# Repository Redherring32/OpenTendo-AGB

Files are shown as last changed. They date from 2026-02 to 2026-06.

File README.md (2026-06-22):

# OpenTendo Game Boy Advance (OpenGBA)

This is an open source recreation of the AGB-CPU-01 board. This was a joint effort between Redherring32 and Bucket Mouse (Mousebitelabs) - initial board scans, copper tracing, and footprint generation were done by Redherring32; schematic and symbol generation, PCB copper cleanup, and silkscreen were done by Bucket Mouse. This is a close to 1:1 recreation of the original AGB-CPU-01 circuit board - some liberties were taken here and there to ensure ease of manufacturability (namely, 6 mil spacing) and to improve aesthetics (most vias are *tented* rather than untented).





## File Structure

**Board Files**: contains the schematics and PCB files for KiCad 9.0

**Footprints/OpenTendo-AGB.pretty**: component footprints for KiCad 9.0

**Symbols**: component symbols for KiCad 9.0

**Bill_of_Materials.csv**: a list of components and component values for each part on the board (see [this site](https://docs.google.com/spreadsheets/d/17RfgOaR-P8M0cC5BojwuY52GbZUefLFm82To7ja963o/edit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) for some alternatives)

**Gerbers.zip**: files used to order circuit boards from manufacturers (JLCPCB, PCBway, etc.)

## Board Characteristics and Order Information

The zipped folder contains all the gerber files for this board. The following options **must** be chosen when ordering boards for yourself.

- Thickness: 1.0mm
- Surface Finish: ENIG

## License
<br />This work is licensed under a <a rel="license" href="http://creativecommons.org/licenses/by-sa/4.0/">Creative Commons Attribution-ShareAlike 4.0 International License</a>. You are able to copy and redistribute the material in any medium or format, as well as remix, transform, or build upon the material for any purpose (even commercial) - but you **must** give appropriate credit, provide a link to the license, and indicate if any changes were made.

©Redherring32 2023-2026

©MouseBiteLabs 2026

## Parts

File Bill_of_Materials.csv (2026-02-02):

Reference | Qty | Value | DNP | Exclude from BOM | Exclude from Board | Footprint | Datasheet
BT1 | 1 | Battery |  |  |  | OpenTendo-AGB:Battery | ~
C1,C37,C62,C63,C64 | 5 | 0.01u |  |  |  | OpenTendo-AGB:C_0402_1005Metric | ~
C2,C24,C28,C30,C38,C42,C57,C61 | 8 | 1u |  |  |  | OpenTendo-AGB:C_0603_1608Metric | ~
C3 | 1 | 27p |  |  |  | OpenTendo-AGB:C_0402_1005Metric | ~
C4 | 1 | 33p |  |  |  | OpenTendo-AGB:C_0402_1005Metric | ~
C5,C6,C7,C8,C13,C14,C15,C16,C17,C22,C23,C26,C32,C34,C39,C40,C41,C45,C46,C47,C50,C51,C52,C53,C55,C58,C59 | 27 | 0.1u |  |  |  | OpenTendo-AGB:C_0402_1005Metric | ~
C9,C12 | 2 | 1000p |  |  |  | OpenTendo-AGB:C_0402_1005Metric | ~
C10,C18,C19,C20,C49 | 5 | 100p |  |  |  | OpenTendo-AGB:C_0402_1005Metric | ~
C11,C48 | 2 | 470p |  |  |  | OpenTendo-AGB:C_0402_1005Metric | ~
C25 | 1 | 0.47u |  |  |  | OpenTendo-AGB:C_0603_1608Metric | ~
C27,C43,C54 | 3 | 4.7u |  |  |  | OpenTendo-AGB:C_0805_2012Metric | ~
C33,C35,C36 | 3 | 1u |  |  |  | OpenTendo-AGB:C_0805_2012Metric | ~
C44,C56 | 2 | 2.2u |  |  |  | OpenTendo-AGB:C_0805_2012Metric | ~
CL1 | 1 | SolderJumper_2_Bridged |  | Excluded from BOM |  | OpenTendo-AGB:Jumper-Bridged | ~
CP1,CP4 | 2 | 100u |  |  |  | OpenTendo-AGB:CP_Elec_5x5.3 | ~
CP2 | 1 | 100u |  |  |  | OpenTendo-AGB:C_Elec_6.3x5.8 | ~
CP3 | 1 | 470u |  |  |  | OpenTendo-AGB:C_Elec_8x10.2 | ~
D1 | 1 | MA112 |  |  |  | OpenTendo-AGB:Diode | ~
D2 | 1 | RB411D |  |  |  | OpenTendo-AGB:SOT-23 | ~
D3 | 1 | RB491D |  |  |  | OpenTendo-AGB:SOT-23 | ~
D4 | 1 | ISS355 |  |  |  | OpenTendo-AGB:Diode | ~
DA1,DA2 | 2 | DA204U |  |  |  | OpenTendo-AGB:SOT-323 | ~
DL1 | 1 | SML311UT |  |  |  | OpenTendo-AGB:LED_0603_1608Metric | ~
DL2 | 1 | SML210MT |  |  |  | OpenTendo-AGB:LED_0603_1608Metric | ~
DZ1 | 1 | RD4.7S |  |  |  | OpenTendo-AGB:Diode
EM1,EM2 | 2 | ACM4532-102-3P |  |  |  | OpenTendo-AGB:EM | ~
EM3,EM7 | 2 | HW601 |  |  |  | OpenTendo-AGB:L_0603_1608Metric | ~
EM4,EM5,EM6 | 3 | BLM11B252SD |  |  |  | OpenTendo-AGB:L_0603_1608Metric | ~
F1 | 1 | 4341.25 |  |  |  | OpenTendo-AGB:Fuse_0603_1608Metric | ~
L1 | 1 | 100u |  |  |  | OpenTendo-AGB:Inductor | ~
P1 | 1 | CART |  |  |  | OpenTendo-AGB:CartSlot
P2 | 1 | LCD |  |  |  | OpenTendo-AGB:LCD-Connector
P3 | 1 | PHONE JACK |  |  |  | OpenTendo-AGB:Audio-Jack
P4 | 1 | AGB-LINK |  |  |  | OpenTendo-AGB:EXT
Q1 | 1 | DTA123J |  |  |  | OpenTendo-AGB:SOT-323
Q2 | 1 | DTA114T |  |  |  | OpenTendo-AGB:SOT-323
Q3,Q10 | 2 | DTC114Y |  |  |  | OpenTendo-AGB:SOT-323
Q4,Q5 | 2 | FDV303N |  |  |  | OpenTendo-AGB:SOT-23 | ~
Q6 | 1 | 2SK1582 |  |  |  | OpenTendo-AGB:SOT-23 | ~
Q7 | 1 | SSM3J01F |  |  |  | OpenTendo-AGB:SOT-23 | ~
Q8,Q9 | 2 | 2SC4081 |  |  |  | OpenTendo-AGB:SOT-323 | ~
Q11 | 1 | DTA114Y |  |  |  | OpenTendo-AGB:SOT-323
R1 | 1 | 1.5M |  |  |  | OpenTendo-AGB:R_0402_1005Metric | ~
R2 | 1 | 10k |  |  |  | OpenTendo-AGB:R_0402_1005Metric | ~
R3,R4,R7,R8,R30,R31 | 6 | 47k |  |  |  | OpenTendo-AGB:R_0402_1005Metric | ~
R5,R6,R17,R35 | 4 | 100k |  |  |  | OpenTendo-AGB:R_0402_1005Metric | ~
R10,R37 | 2 | 470 |  |  |  | OpenTendo-AGB:R_0402_1005Metric | ~
R11,R12,R13 | 3 | 150 |  |  |  | OpenTendo-AGB:R_0402_1005Metric | ~
R14 | 1 | 4.7k |  |  |  | OpenTendo-AGB:R_0402_1005Metric | ~
R15,R16,R18 | 3 | 33k |  |  |  | OpenTendo-AGB:R_0402_1005Metric | ~
R19,R20,R40,R43,R44 | 5 | 15 |  |  |  | OpenTendo-AGB:R_0402_1005Metric | ~
R25,R38,R39 | 3 | 47 |  |  |  | OpenTendo-AGB:R_0402_1005Metric | ~
R26,R34 | 2 | 15k |  |  |  | OpenTendo-AGB:R_0402_1005Metric | ~
R27 | 1 | 200k |  |  |  | OpenTendo-AGB:R_0402_1005Metric | ~
R28 | 1 | 56k |  |  |  | OpenTendo-AGB:R_0402_1005Metric | ~
R29 | 1 | 18k |  |  |  | OpenTendo-AGB:R_0402_1005Metric | ~
R32 | 1 | 1M |  |  |  | OpenTendo-AGB:R_0402_1005Metric | ~
R33 | 1 | 5.1 |  |  |  | OpenTendo-AGB:R_0402_1005Metric | ~
R36 | 1 | 270 |  |  |  | OpenTendo-AGB:R_0402_1005Metric | ~
R41 | 1 | 2.2k |  |  |  | OpenTendo-AGB:R_0402_1005Metric | ~
RA1 | 1 | 330 |  |  |  | OpenTendo-AGB:RA
SP1 | 1 | Speaker |  |  |  | OpenTendo-AGB:Speaker | ~
SW1 | 1 | AGB-SW |  |  |  | OpenTendo-AGB:Power Switch
SW2 | 1 | SW_Push |  |  |  | OpenTendo-AGB:L | ~
SW3 | 1 | SW_Push |  |  |  | OpenTendo-AGB:R | ~
SW4 | 1 | AGB-A-B |  |  |  | OpenTendo-AGB:AB | ~
SW5 | 1 | AGB-ST-SEL |  |  |  | OpenTendo-AGB:StartSelect
SW6 | 1 | AGB-DPAD |  |  |  | OpenTendo-AGB:DPAD
T1 | 1 | AGB-XFRM |  |  |  | OpenTendo-AGB:Coil
TP0 | 1 | TP0 |  |  |  | OpenTendo-AGB:TestPoint_Pad_D1.0mm
TP1 | 1 | TP1 |  |  |  | OpenTendo-AGB:TestPoint_Pad_D1.0mm
TP2 | 1 | TP2 |  |  |  | OpenTendo-AGB:TestPoint_Pad_D0.8mm
TP3 | 1 | TP3 |  |  |  | OpenTendo-AGB:TestPoint_Pad_D0.8mm
TP4 | 1 | TP4 |  |  |  | OpenTendo-AGB:TestPoint_Pad_D0.8mm
TP5 | 1 | TP5 |  |  |  | OpenTendo-AGB:TestPoint_Pad_D1.0mm
TP6 | 1 | TP6 |  |  |  | OpenTendo-AGB:TestPoint_Pad_D0.8mm
TP7 | 1 | TP7 |  |  |  | OpenTendo-AGB:TestPoint_Pad_D1.0mm
TP8 | 1 | TP8 |  |  |  | OpenTendo-AGB:TestPoint_Pad_D0.8mm_VIA
TP9 | 1 | TP9 |  |  |  | OpenTendo-AGB:TestPoint_Pad_D0.8mm
TP10 | 1 | VOUT3 |  |  |  | OpenTendo-AGB:TestPoint_Pad_D1.0mm_VIA
TP11 | 1 | VDRV3 |  |  |  | OpenTendo-AGB:TestPoint_Pad_D1.0mm
TP12 | 1 | VDD2 |  |  |  | OpenTendo-AGB:TestPoint_Pad_D0.8mm
TP13 | 1 | VDRV5 |  |  |  | OpenTendo-AGB:TestPoint_Pad_D1.0mm
TP14 | 1 | VOUT5 |  |  |  | OpenTendo-AGB:TestPoint_Pad_D0.8mm
TP15 | 1 | ~{RESET} |  |  |  | OpenTendo-AGB:TestPoint_Pad_D1.25mm_VIA
TP16 | 1 | D3A |  |  |  | OpenTendo-AGB:TestPoint_Pad_D1.0mm
TP17 | 1 | D2A |  |  |  | OpenTendo-AGB:TestPoint_Pad_D1.0mm_VIA
TP18 | 1 | DA2-AC |  |  |  | OpenTendo-AGB:TestPoint_Pad_D0.8mm_VIA
TP19 | 1 | DA1-AC |  |  |  | OpenTendo-AGB:TestPoint_Pad_D1.0mm_VIA
TP20 | 1 | DA2-A |  |  |  | OpenTendo-AGB:TestPoint_Pad_D0.8mm
TP21 | 1 | DA1-C |  |  |  | OpenTendo-AGB:TestPoint_Pad_D0.8mm
TP22 | 1 | VDD13 |  |  |  | OpenTendo-AGB:TestPoint_Pad_D0.8mm
TP23 | 1 | VDD-15 |  |  |  | OpenTendo-AGB:TestPoint_Pad_D1.0mm
TP24 | 1 | VDD5 |  |  |  | OpenTendo-AGB:TestPoint_Pad_D1.0mm
TP25 | 1 | Q8B |  |  |  | OpenTendo-AGB:TestPoint_Pad_D0.8mm
TP26 | 1 | VSHD |  |  |  | OpenTendo-AGB:TestPoint_Pad_D0.8mm
TP27 | 1 | Q10B |  |  |  | OpenTendo-AGB:TestPoint_Pad_D0.8mm_VIA
TP28 | 1 | LOWBAT |  |  |  | OpenTendo-AGB:TestPoint_Pad_D0.8mm
TP29 | 1 | DL2A |  |  |  | OpenTendo-AGB:TestPoint_Pad_D0.8mm_VIA
TP30 | 1 | DL2K |  |  |  | OpenTendo-AGB:TestPoint_Pad_D0.8mm_VIA
TP31 | 1 | DL1A |  |  |  | OpenTendo-AGB:TestPoint_Pad_D0.8mm_VIA
TP32 | 1 | D1A |  |  |  | OpenTendo-AGB:TestPoint_Pad_D0.8mm_VIA
TP33 | 1 | Q9C |  |  |  | OpenTendo-AGB:TestPoint_Pad_D1.0mm
TP34 | 1 | Q9B |  |  |  | OpenTendo-AGB:TestPoint_Pad_D0.8mm
TP35 | 1 | Q11B |  |  |  | OpenTendo-AGB:TestPoint_Pad_D0.8mm_VIA
TP36 | 1 | MOD |  |  |  | OpenTendo-AGB:TestPoint_Pad_D0.8mm_VIA
TP37 | 1 | SPS |  |  |  | OpenTendo-AGB:TestPoint_Pad_D0.8mm_VIA
TP38 | 1 | CLS |  |  |  | OpenTendo-AGB:TestPoint_Pad_D0.8mm_VIA
TP39 | 1 | SPL |  |  |  | OpenTendo-AGB:TestPoint_Pad_D0.8mm_VIA
TP40 | 1 | LDB1 |  |  |  | OpenTendo-AGB:TestPoint_Pad_D0.8mm_VIA
TP41 | 1 | LDB2 |  |  |  | OpenTendo-AGB:TestPoint_Pad_D0.8mm_VIA
TP42 | 1 | LDB3 |  |  |  | OpenTendo-AGB:TestPoint_Pad_D0.8mm_VIA
TP43 | 1 | LDB4 |  |  |  | OpenTendo-AGB:TestPoint_Pad_D0.8mm_VIA
TP44 | 1 | LDB5 |  |  |  | OpenTendo-AGB:TestPoint_Pad_D0.8mm_VIA
TP45 | 1 | LDG1 |  |  |  | OpenTendo-AGB:TestPoint_Pad_D0.8mm_VIA
TP46 | 1 | LDG2 |  |  |  | OpenTendo-AGB:TestPoint_Pad_D0.8mm_VIA
TP47 | 1 | LDG3 |  |  |  | OpenTendo-AGB:TestPoint_Pad_D0.8mm_VIA
TP48 | 1 | LDG4 |  |  |  | OpenTendo-AGB:TestPoint_Pad_D0.8mm_VIA
TP49 | 1 | LDG5 |  |  |  | OpenTendo-AGB:TestPoint_Pad_D0.8mm_VIA
TP50 | 1 | LDR1 |  |  |  | OpenTendo-AGB:TestPoint_Pad_D0.8mm_VIA
TP51 | 1 | LDR2 |  |  |  | OpenTendo-AGB:TestPoint_Pad_D0.8mm_VIA
TP52 | 1 | LDR3 |  |  |  | OpenTendo-AGB:TestPoint_Pad_D0.8mm_VIA
TP53 | 1 | LDR4 |  |  |  | OpenTendo-AGB:TestPoint_Pad_D0.8mm_VIA
TP54 | 1 | LDR5 |  |  |  | OpenTendo-AGB:TestPoint_Pad_D0.8mm_VIA
TP55 | 1 | PS |  |  |  | OpenTendo-AGB:TestPoint_Pad_D0.8mm_VIA
TP56 | 1 | LP |  |  |  | OpenTendo-AGB:TestPoint_Pad_D0.8mm_VIA
TP57 | 1 | DCK |  |  |  | OpenTendo-AGB:TestPoint_Pad_D0.8mm
TP58 | 1 | P2-VSS |  |  |  | OpenTendo-AGB:TestPoint_Pad_D0.8mm
TP59 | 1 | P2-VCC |  |  |  | OpenTendo-AGB:TestPoint_Pad_D0.8mm
TP60 | 1 | P2-VDD |  |  |  | OpenTendo-AGB:TestPoint_Pad_D0.8mm_VIA
TP61 | 1 | P2-VEE |  |  |  | OpenTendo-AGB:TestPoint_Pad_D0.8mm_VIA
TP62 | 1 | REVC |  |  |  | OpenTendo-AGB:TestPoint_Pad_D0.8mm
TP63 | 1 | U3-VDD |  |  |  | OpenTendo-AGB:TestPoint_Pad_D0.8mm
TP64 | 1 | V0 |  |  |  | OpenTendo-AGB:TestPoint_Pad_D0.8mm
TP65 | 1 | V1 |  |  |  | OpenTendo-AGB:TestPoint_Pad_D0.8mm
TP66 | 1 | V2 |  |  |  | OpenTendo-AGB:TestPoint_Pad_D0.8mm
TP67 | 1 | V3 |  |  |  | OpenTendo-AGB:TestPoint_Pad_D0.8mm_VIA
TP68 | 1 | V4 |  |  |  | OpenTendo-AGB:TestPoint_Pad_D0.8mm
TP69 | 1 | U3-COM |  |  |  | OpenTendo-AGB:TestPoint_Pad_D0.8mm
TP70 | 1 | VCOM |  |  |  | OpenTendo-AGB:TestPoint_Pad_D0.8mm_VIA
TP71 | 1 | VR1-2 |  |  |  | OpenTendo-AGB:TestPoint_Pad_D0.8mm_VIA
TP72 | 1 | U5-3 |  |  |  | OpenTendo-AGB:TestPoint_Pad_D0.8mm_VIA
TP73 | 1 | Q3B |  |  |  | OpenTendo-AGB:TestPoint_Pad_D0.8mm_VIA
TP74 | 1 | Q1B |  |  |  | OpenTendo-AGB:TestPoint_Pad_D0.8mm_VIA
TP75 | 1 | IN35 |  |  |  | OpenTendo-AGB:TestPoint_Pad_D1.0mm_VIA
TP76 | 1 | VDD35 |  |  |  | OpenTendo-AGB:TestPoint_Pad_D1.0mm
TP77 | 1 | PHI |  |  |  | OpenTendo-AGB:TestPoint_Pad_D1.0mm
TP78 | 1 | RES |  |  |  | OpenTendo-AGB:TestPoint_Pad_D0.8mm_VIA
TP79 | 1 | P1-GND |  |  |  | OpenTendo-AGB:TestPoint_Pad_D1.0mm
TP80 | 1 | CK1 |  |  |  | OpenTendo-AGB:TestPoint_Pad_D0.8mm
TP81 | 1 | CK2 |  |  |  | OpenTendo-AGB:TestPoint_Pad_D0.8mm
TP82 | 1 | FIQ |  |  |  | OpenTendo-AGB:TestPoint_Pad_D1.25mm_VIA
TP83 | 1 | SW1-2 |  |  |  | OpenTendo-AGB:TestPoint_Pad_D1.25mm
TP84 | 1 | SW1-1 |  |  |  | OpenTendo-AGB:TestPoint_Pad_D0.8mm
TP85 | 1 | VCC |  |  |  | OpenTendo-AGB:TestPoint_Pad_D0.8mm
TP86 | 1 | C_SCP |  |  |  | OpenTendo-AGB:TestPoint_Pad_D1.0mm
TP87 | 1 | C_SS5 |  |  |  | OpenTendo-AGB:TestPoint_Pad_D1.0mm
TP88 | 1 | C_SS3 |  |  |  | OpenTendo-AGB:TestPoint_Pad_D1.0mm
TP89 | 1 | VIN |  |  |  | OpenTendo-AGB:TestPoint_Pad_D0.8mm_VIA
TP90 | 1 | REG_EXT |  |  |  | OpenTendo-AGB:TestPoint_Pad_D0.8mm
TP91 | 1 | VCNT5 |  |  |  | OpenTendo-AGB:TestPoint_Pad_D1.0mm
TP92 | 1 | SO |  |  |  | OpenTendo-AGB:TestPoint_Pad_D0.8mm
TP93 | 1 | SD |  |  |  | OpenTendo-AGB:TestPoint_Pad_D0.8mm_VIA
TP94 | 1 | SI |  |  |  | OpenTendo-AGB:TestPoint_Pad_D0.8mm
TP95 | 1 | SCK |  |  |  | OpenTendo-AGB:TestPoint_Pad_D0.8mm_VIA
TP96 | 1 | U6-LIN |  |  |  | OpenTendo-AGB:TestPoint_Pad_D0.8mm
TP97 | 1 | U6-RIN |  |  |  | OpenTendo-AGB:TestPoint_Pad_D0.8mm
TP98 | 1 | FL |  |  |  | OpenTendo-AGB:TestPoint_Pad_D0.8mm
TP99 | 1 | FR |  |  |  | OpenTendo-AGB:TestPoint_Pad_D0.8mm
TP100 | 1 | FL1 |  |  |  | OpenTendo-AGB:TestPoint_Pad_D0.8mm
TP101 | 1 | FL2 |  |  |  | OpenTendo-AGB:TestPoint_Pad_D0.8mm
TP102 | 1 | FR1 |  |  |  | OpenTendo-AGB:TestPoint_Pad_D0.8mm
TP103 | 1 | FR2 |  |  |  | OpenTendo-AGB:TestPoint_Pad_D0.8mm
TP104 | 1 | U6-LOUT |  |  |  | OpenTendo-AGB:TestPoint_Pad_D0.8mm_VIA
TP105 | 1 | U6-ROUT |  |  |  | OpenTendo-AGB:TestPoint_Pad_D0.8mm
TP106 | 1 | VOL |  |  |  | OpenTendo-AGB:TestPoint_Pad_D0.8mm_VIA
TP107 | 1 | VR2-3 |  |  |  | OpenTendo-AGB:TestPoint_Pad_D0.8mm_VIA
TP108 | 1 | VR2-1 |  |  |  | OpenTendo-AGB:TestPoint_Pad_D0.8mm_VIA
TP109 | 1 | LOUT |  |  |  | OpenTendo-AGB:TestPoint_Pad_D0.8mm
TP110 | 1 | ROUT |  |  |  | OpenTendo-AGB:TestPoint_Pad_D0.8mm
TP111 | 1 | SP |  |  |  | OpenTendo-AGB:TestPoint_Pad_D1.25mm_VIA
TP112 | 1 | A-GND |  |  |  | OpenTendo-AGB:TestPoint_Pad_D1.0mm
TP113 | 1 | VDD3 |  |  |  | OpenTendo-AGB:TestPoint_Pad_D0.8mm
TP114 | 1 | R-OUT |  |  |  | OpenTendo-AGB:TestPoint_Pad_D0.8mm
TP115 | 1 | L-OUT |  |  |  | OpenTendo-AGB:TestPoint_Pad_D0.8mm
TP116 | 1 | T1-6 |  |  |  | OpenTendo-AGB:TestPoint_Pad_D1.0mm_VIA
U1 | 1 | AGB-CPU |  |  |  | OpenTendo-AGB:CPU-AGB
U2 | 1 | AGB-SRAM |  |  |  | OpenTendo-AGB:AGB-SRAM
U3 | 1 | AGB-REG |  |  |  | OpenTendo-AGB:AGB-REG
U4 | 1 | AGB-PMIC |  |  |  | OpenTendo-AGB:TSSOP-16_4.4x5mm_P0.65mm
U5 | 1 | UMD2N |  |  |  | OpenTendo-AGB:SOT-363_SC-70-6
U6 | 1 | AGB-AMP |  |  |  | OpenTendo-AGB:AGB-AMP
U10 | 1 | UMG3N |  |  |  | OpenTendo-AGB:SOT-353_SC-70-5
VR1 | 1 | 50k |  |  |  | OpenTendo-AGB:VR1 | ~
VR2 | 1 | 30k |  |  |  | OpenTendo-AGB:Thumbwheel | ~
X1 | 1 | 4.194304MHz |  |  |  | OpenTendo-AGB:Crystal | ~

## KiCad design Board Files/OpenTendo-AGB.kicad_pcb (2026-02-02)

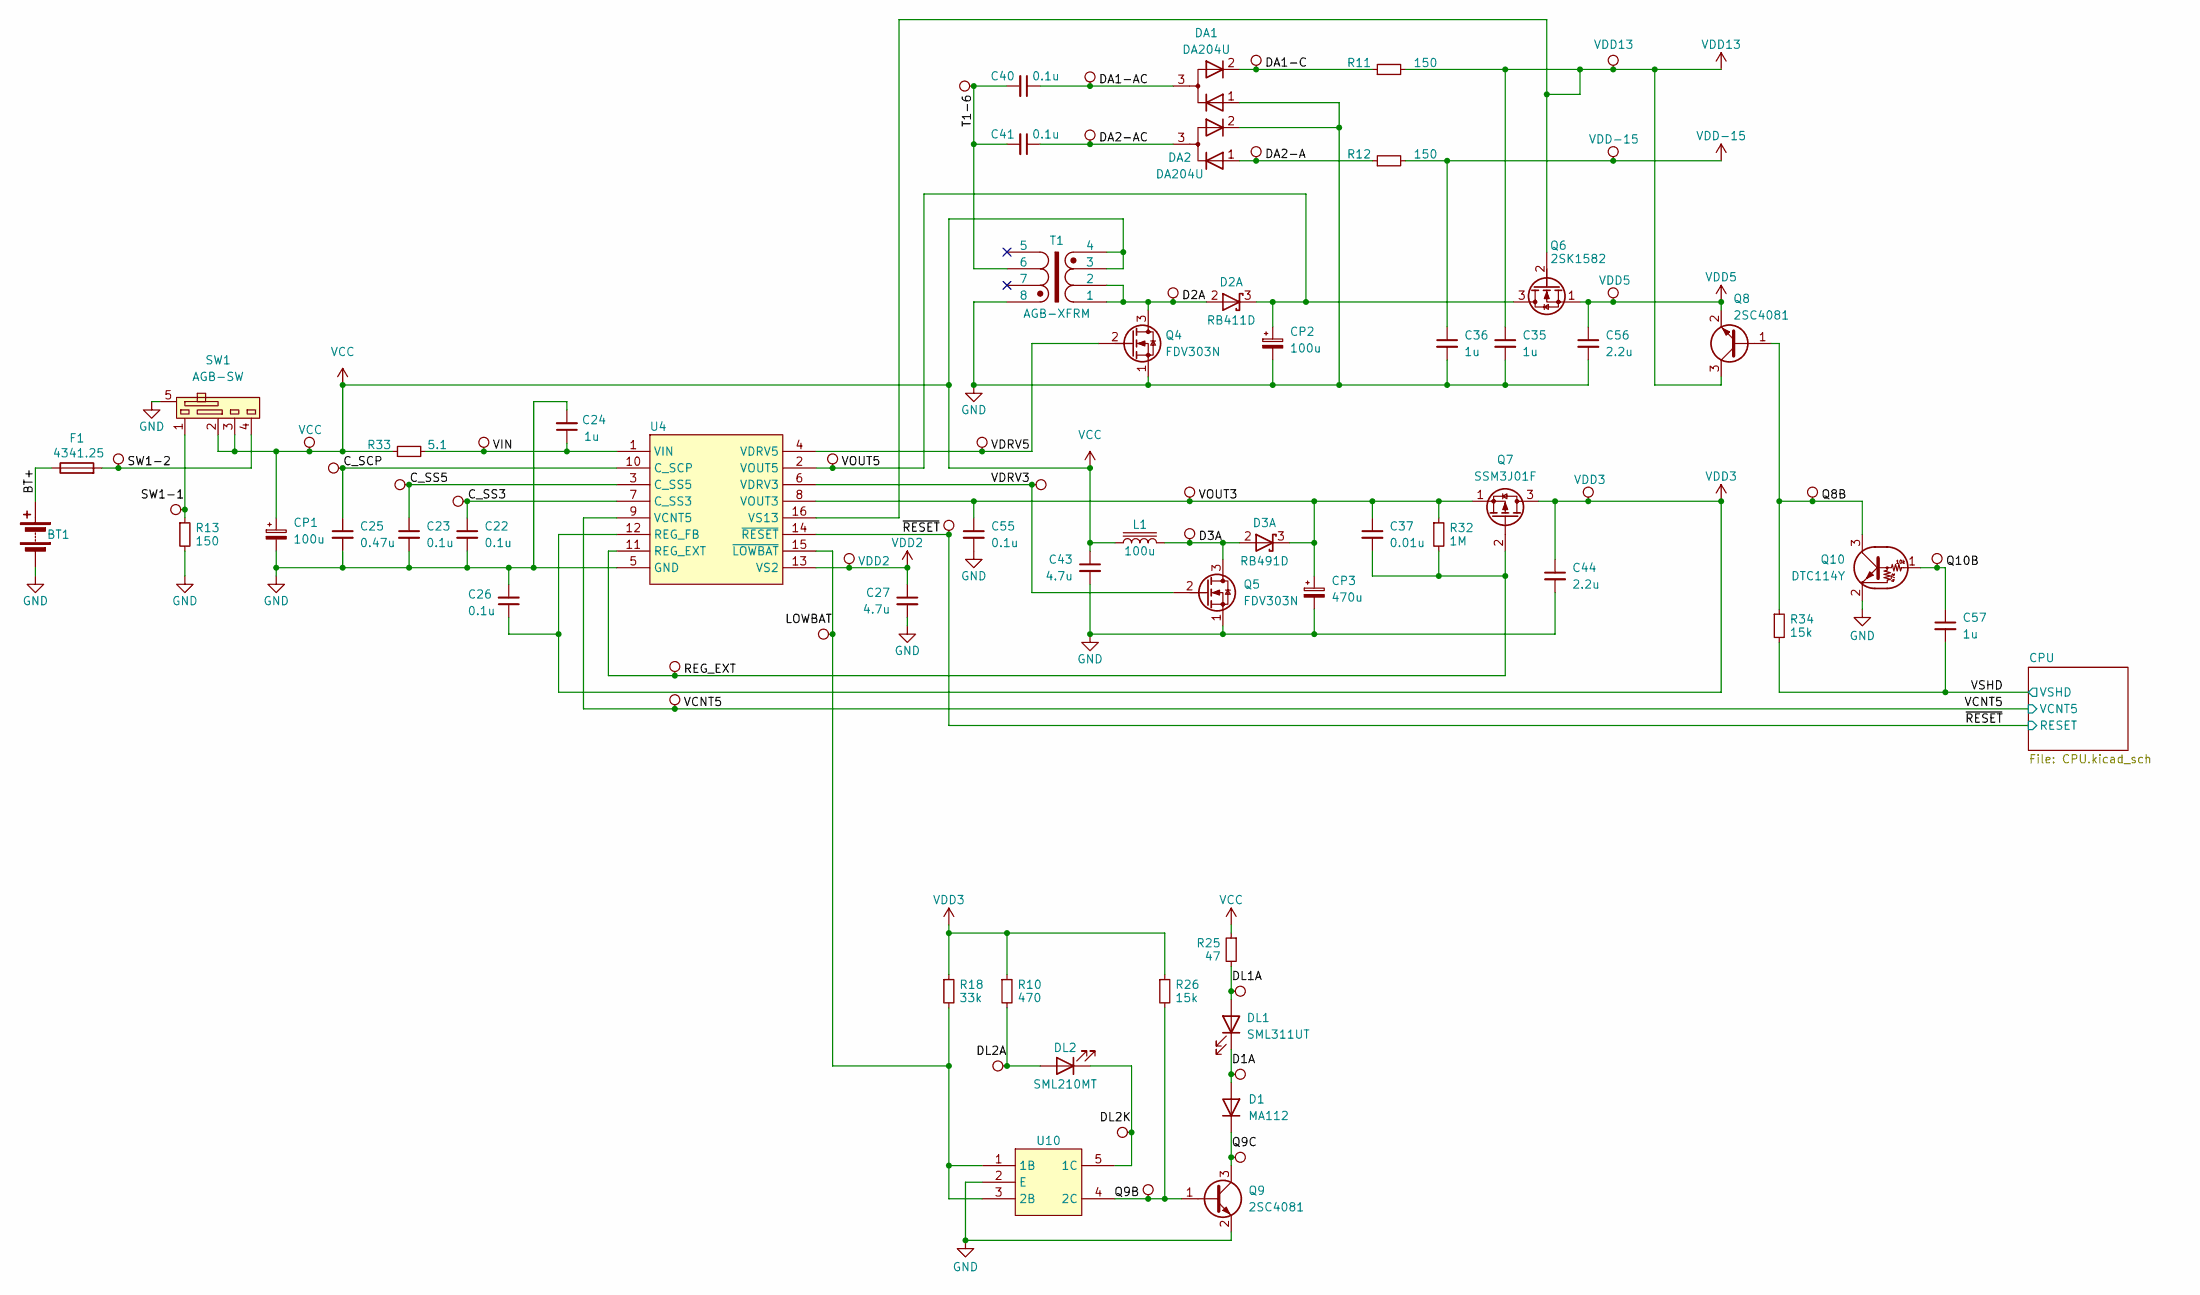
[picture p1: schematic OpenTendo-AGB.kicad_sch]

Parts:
BT1: Battery
C22, C23, C26, C40, C41, C55: 0.1u; C_0402_1005Metric
C24, C57: 1u; C_0603_1608Metric
C25: 0.47u; C_0603_1608Metric
C27, C43: 4.7u; C_0805_2012Metric
C35, C36: 1u; C_0805_2012Metric
C37: 0.01u; C_0402_1005Metric
C44, C56: 2.2u; C_0805_2012Metric
CP1: 100u; CP_Elec_5x5.3
CP2: 100u; C_Elec_6.3x5.8
CP3: 470u; C_Elec_8x10.2
D1: MA112; Diode
D2: RB411D; SOT-23
D3: RB491D; SOT-23
DA1, DA2: DA204U; SOT-323
DL1: SML311UT; LED_0603_1608Metric
DL2: SML210MT; LED_0603_1608Metric
F1: 4341.25; Fuse_0603_1608Metric
L1: 100u; Inductor
Q4, Q5: FDV303N; SOT-23
Q6: 2SK1582; SOT-23
Q7: SSM3J01F; SOT-23
Q8, Q9: 2SC4081; SOT-323
Q10: DTC114Y; SOT-323
R10: 470; R_0402_1005Metric
R11, R12, R13: 150; R_0402_1005Metric
R18: 33k; R_0402_1005Metric
R25: 47; R_0402_1005Metric
R26, R34: 15k; R_0402_1005Metric
R32: 1M; R_0402_1005Metric
R33: 5.1; R_0402_1005Metric
SW1: AGB-SW; Power Switch
T1: AGB-XFRM; Coil
TP10: VOUT3; TestPoint_Pad_D1.0mm_VIA
TP11: VDRV3; TestPoint_Pad_D1.0mm
TP12: VDD2; TestPoint_Pad_D0.8mm
TP13: VDRV5; TestPoint_Pad_D1.0mm
TP14: VOUT5; TestPoint_Pad_D0.8mm
TP15: ~{RESET}; TestPoint_Pad_D1.25mm_VIA
TP16: D3A; TestPoint_Pad_D1.0mm
TP17: D2A; TestPoint_Pad_D1.0mm_VIA
TP18: DA2-AC; TestPoint_Pad_D0.8mm_VIA
TP19: DA1-AC; TestPoint_Pad_D1.0mm_VIA
TP20: DA2-A; TestPoint_Pad_D0.8mm
TP21: DA1-C; TestPoint_Pad_D0.8mm
TP22: VDD13; TestPoint_Pad_D0.8mm
TP23: VDD-15; TestPoint_Pad_D1.0mm
TP24: VDD5; TestPoint_Pad_D1.0mm
TP25: Q8B; TestPoint_Pad_D0.8mm
TP27: Q10B; TestPoint_Pad_D0.8mm_VIA
TP28: LOWBAT; TestPoint_Pad_D0.8mm
TP29: DL2A; TestPoint_Pad_D0.8mm_VIA
TP30: DL2K; TestPoint_Pad_D0.8mm_VIA
TP31: DL1A; TestPoint_Pad_D0.8mm_VIA
TP32: D1A; TestPoint_Pad_D0.8mm_VIA
TP33: Q9C; TestPoint_Pad_D1.0mm
TP34: Q9B; TestPoint_Pad_D0.8mm
TP83: SW1-2; TestPoint_Pad_D1.25mm
TP84: SW1-1; TestPoint_Pad_D0.8mm
TP85: VCC; TestPoint_Pad_D0.8mm
TP86: C_SCP; TestPoint_Pad_D1.0mm
TP87: C_SS5; TestPoint_Pad_D1.0mm
TP88: C_SS3; TestPoint_Pad_D1.0mm
TP89: VIN; TestPoint_Pad_D0.8mm_VIA
TP90: REG_EXT; TestPoint_Pad_D0.8mm
TP91: VCNT5; TestPoint_Pad_D1.0mm
TP113: VDD3; TestPoint_Pad_D0.8mm
TP116: T1-6; TestPoint_Pad_D1.0mm_VIA
U4: AGB-PMIC; TSSOP-16_4.4x5mm_P0.65mm
U10: UMG3N; SOT-353_SC-70-5

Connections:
/BT+: BT1.1 (+), F1.1
/C_SCP: C25.1, TP86.1, U4.10 (C_SCP)
/C_SS3: C22.1, TP88.1, U4.7 (C_SS3)
/C_SS5: C23.1, TP87.1, U4.3 (C_SS5)
/D1A: D1.2 (A), DL1.1 (K), TP32.1
/D2A: D2.2 (A), Q4.3 (D), T1.1, T1.2, TP17.1
/D3A: D3.2 (A), L1.2, Q5.3 (D), TP16.1
/DA1-AC: C40.1, DA1.3 (common), TP19.1
/DA1-C: DA1.2 (K), R11.1, TP21.1
/DA2-A: DA2.1 (A), R12.1, TP20.1
/DA2-AC: C41.1, DA2.3 (common), TP18.1
/DL1A: DL1.2 (A), R25.2, TP31.1
/DL2A: DL2.2 (A), R10.2, TP29.1
/DL2K: DL2.1 (K), TP30.1, U10.5 (1C)
/LOWBAT: R18.2, TP28.1, U4.15 (~LOWBAT), U10.1 (1B), U10.3 (2B)
/Q8B: Q8.1 (B), Q10.3 (C), R34.1, TP25.1
/Q9B: Q9.1 (B), R26.2, TP34.1, U10.4 (2C)
/Q9C: D1.1 (K), Q9.3 (C), TP33.1
/Q10B: C57.1, Q10.1 (B), TP27.1
/REG_EXT: C37.2, Q7.2 (G), R32.2, TP90.1, U4.11 (REG_EXT)
/SW1-1: R13.1, SW1.1, TP84.1
/SW1-2: F1.2, SW1.4 (2), TP83.1
/T1-6: C40.2, C41.2, T1.6, TP116.1
/VCNT5: TP91.1, U4.9 (VCNT5); also elsewhere on the board
/VDRV3: Q5.2 (G), TP11.1, U4.6 (VDRV3)
/VDRV5: Q4.2 (G), TP13.1, U4.4 (VDRV5)
/VIN: C24.1, R33.2, TP89.1, U4.1 (VIN)
/VOUT3: C37.1, C55.1, CP3.1, D3.3 (K), Q7.1 (S), R32.1, TP10.1, U4.8 (VOUT3)
/VOUT5: CP2.1, D2.3 (K), Q6.3 (D), TP14.1, U4.2 (VOUT5)
/VSHD: C57.2, R34.2; also elsewhere on the board
/~RESET: TP15.1, U4.14 (~RESET); also elsewhere on the board
GND: BT1.2 (-), C22.2, C23.2, C24.2, C25.2, C26.2, C27.2, C35.2, C36.2, C43.2, C44.2, C55.2, C56.2, CP1.2, CP2.2, CP3.2, DA1.1 (A), DA2.2 (K), Q4.1 (S), Q5.1 (S), Q9.2 (E), Q10.2 (E), R13.2, SW1.5 (SH), T1.8, U4.5 (GND), U10.2 (E); also elsewhere on the board
VCC: C43.1, CP1.1, L1.1, R25.1, R33.1, SW1.2 (C), SW1.3 (C), T1.3, T1.4, TP85.1; also elsewhere on the board
VDD2: C27.1, TP12.1, U4.13 (VS2); also elsewhere on the board
VDD3: C26.1, C44.1, Q7.3 (D), R10.1, R18.1, R26.1, TP113.1, U4.12 (REG_FB); also elsewhere on the board
VDD5: C56.1, Q6.1 (S), Q8.2 (E), TP24.1; also elsewhere on the board
VDD13: C35.1, Q6.2 (G), Q8.3 (C), R11.2, TP22.1, U4.16 (VS13); also elsewhere on the board
VDD-15: C36.1, R12.2, TP23.1; also elsewhere on the board

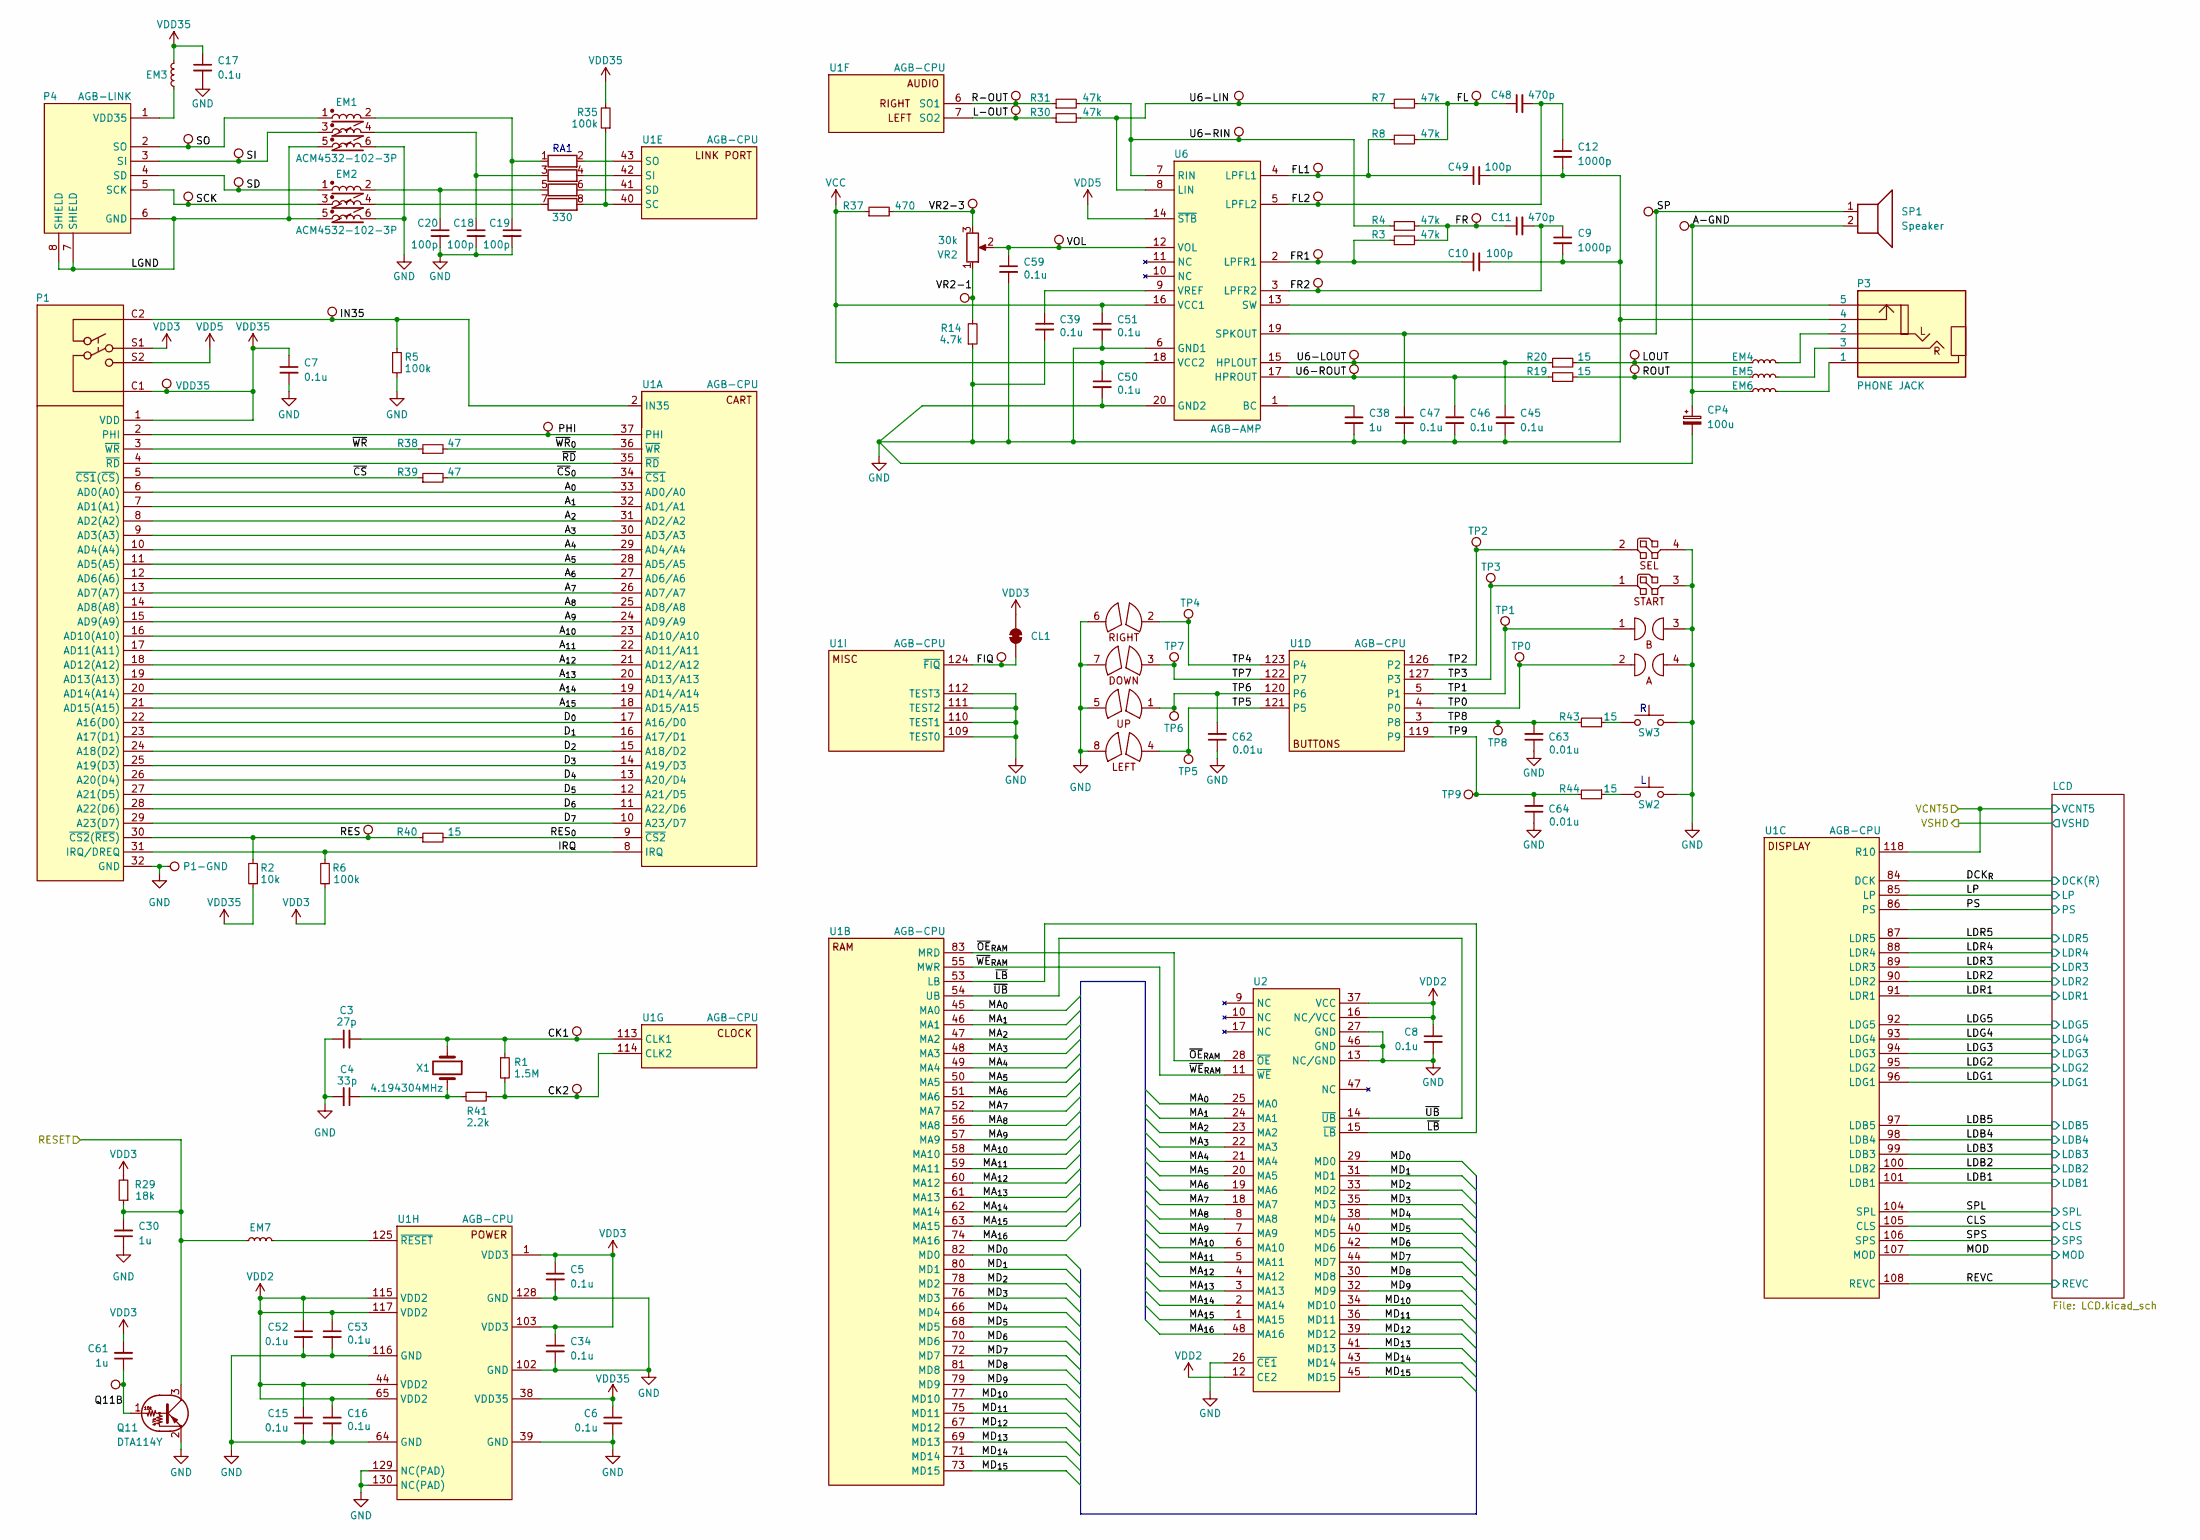
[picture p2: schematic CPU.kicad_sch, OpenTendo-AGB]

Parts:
C3: 27p; C_0402_1005Metric
C4: 33p; C_0402_1005Metric
C5, C6, C7, C8, C15, C16, C17, C34, C39, C45, C46, C47, C50, C51, C52, C53, C59: 0.1u; C_0402_1005Metric
C9, C12: 1000p; C_0402_1005Metric
C10, C18, C19, C20, C49: 100p; C_0402_1005Metric
C11, C48: 470p; C_0402_1005Metric
C30, C38, C61: 1u; C_0603_1608Metric
C62, C63, C64: 0.01u; C_0402_1005Metric
CL1: SolderJumper_2_Bridged; Jumper-Bridged
CP4: 100u; CP_Elec_5x5.3
EM1, EM2: ACM4532-102-3P; EM
EM3, EM7: HW601; L_0603_1608Metric
EM4, EM5, EM6: BLM11B252SD; L_0603_1608Metric
P1: CART; CartSlot
P3: PHONE JACK; Audio-Jack
P4: AGB-LINK; EXT
Q11: DTA114Y; SOT-323
R1: 1.5M; R_0402_1005Metric
R2: 10k; R_0402_1005Metric
R3, R4, R7, R8, R30, R31: 47k; R_0402_1005Metric
R5, R6, R35: 100k; R_0402_1005Metric
R14: 4.7k; R_0402_1005Metric
R19, R20, R40, R43, R44: 15; R_0402_1005Metric
R29: 18k; R_0402_1005Metric
R37: 470; R_0402_1005Metric
R38, R39: 47; R_0402_1005Metric
R41: 2.2k; R_0402_1005Metric
RA1: 330; RA
SP1: Speaker
SW2: SW_Push; L
SW3: SW_Push; R
SW4: AGB-A-B; AB
SW5: AGB-ST-SEL; StartSelect
SW6: AGB-DPAD; DPAD
TP0: TP0; TestPoint_Pad_D1.0mm
TP1: TP1; TestPoint_Pad_D1.0mm
TP2: TP2; TestPoint_Pad_D0.8mm
TP3: TP3; TestPoint_Pad_D0.8mm
TP4: TP4; TestPoint_Pad_D0.8mm
TP5: TP5; TestPoint_Pad_D1.0mm
TP6: TP6; TestPoint_Pad_D0.8mm
TP7: TP7; TestPoint_Pad_D1.0mm
TP8: TP8; TestPoint_Pad_D0.8mm_VIA
TP9: TP9; TestPoint_Pad_D0.8mm
TP35: Q11B; TestPoint_Pad_D0.8mm_VIA
TP75: IN35; TestPoint_Pad_D1.0mm_VIA
TP76: VDD35; TestPoint_Pad_D1.0mm
TP77: PHI; TestPoint_Pad_D1.0mm
TP78: RES; TestPoint_Pad_D0.8mm_VIA
TP79: P1-GND; TestPoint_Pad_D1.0mm
TP80: CK1; TestPoint_Pad_D0.8mm
TP81: CK2; TestPoint_Pad_D0.8mm
TP82: FIQ; TestPoint_Pad_D1.25mm_VIA
TP92: SO; TestPoint_Pad_D0.8mm
TP93: SD; TestPoint_Pad_D0.8mm_VIA
TP94: SI; TestPoint_Pad_D0.8mm
TP95: SCK; TestPoint_Pad_D0.8mm_VIA
TP96: U6-LIN; TestPoint_Pad_D0.8mm
TP97: U6-RIN; TestPoint_Pad_D0.8mm
TP98: FL; TestPoint_Pad_D0.8mm
TP99: FR; TestPoint_Pad_D0.8mm
TP100: FL1; TestPoint_Pad_D0.8mm
TP101: FL2; TestPoint_Pad_D0.8mm
TP102: FR1; TestPoint_Pad_D0.8mm
TP103: FR2; TestPoint_Pad_D0.8mm
TP104: U6-LOUT; TestPoint_Pad_D0.8mm_VIA
TP105: U6-ROUT; TestPoint_Pad_D0.8mm
TP106: VOL; TestPoint_Pad_D0.8mm_VIA
TP107: VR2-3; TestPoint_Pad_D0.8mm_VIA
TP108: VR2-1; TestPoint_Pad_D0.8mm_VIA
TP109: LOUT; TestPoint_Pad_D0.8mm
TP110: ROUT; TestPoint_Pad_D0.8mm
TP111: SP; TestPoint_Pad_D1.25mm_VIA
TP112: A-GND; TestPoint_Pad_D1.0mm
TP114: R-OUT; TestPoint_Pad_D0.8mm
TP115: L-OUT; TestPoint_Pad_D0.8mm
U1: AGB-CPU; CPU-AGB
U2: AGB-SRAM
U6: AGB-AMP
VR2: 30k; Thumbwheel
X1: 4.194304MHz; Crystal

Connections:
/CPU/A-GND: CP4.1, EM6.1, SP1.2, TP112.1
/CPU/A_{0}: P1.6 (AD0(A0)), U1.33 (AD0/A0)
/CPU/A_{1}: P1.7 (AD1(A1)), U1.32 (AD1/A1)
/CPU/A_{2}: P1.8 (AD2(A2)), U1.31 (AD2/A2)
/CPU/A_{3}: P1.9 (AD3(A3)), U1.30 (AD3/A3)
/CPU/A_{4}: P1.10 (AD4(A4)), U1.29 (AD4/A4)
/CPU/A_{5}: P1.11 (AD5(A5)), U1.28 (AD5/A5)
/CPU/A_{6}: P1.12 (AD6(A6)), U1.27 (AD6/A6)
/CPU/A_{7}: P1.13 (AD7(A7)), U1.26 (AD7/A7)
/CPU/A_{8}: P1.14 (AD8(A8)), U1.25 (AD8/A8)
/CPU/A_{9}: P1.15 (AD9(A9)), U1.24 (AD9/A9)
/CPU/A_{10}: P1.16 (AD10(A10)), U1.23 (AD10/A10)
/CPU/A_{11}: P1.17 (AD11(A11)), U1.22 (AD11/A11)
/CPU/A_{12}: P1.18 (AD12(A12)), U1.21 (AD12/A12)
/CPU/A_{13}: P1.19 (AD13(A13)), U1.20 (AD13/A13)
/CPU/A_{14}: P1.20 (AD14(A14)), U1.19 (AD14/A14)
/CPU/A_{15}: P1.21 (AD15(A15)), U1.18 (AD15/A15)
/CPU/CK1: C3.2, R1.1, TP80.1, U1.113 (CLK1), X1.1
/CPU/CK2: R1.2, R41.1, TP81.1, U1.114 (CLK2)
/CPU/CLS: U1.105 (CLS); also elsewhere on the board
/CPU/DCK_{R}: U1.84 (DCK); also elsewhere on the board
/CPU/D_{0}: P1.22 (A16(D0)), U1.17 (A16/D0)
/CPU/D_{1}: P1.23 (A17(D1)), U1.16 (A17/D1)
/CPU/D_{2}: P1.24 (A18(D2)), U1.15 (A18/D2)
/CPU/D_{3}: P1.25 (A19(D3)), U1.14 (A19/D3)
/CPU/D_{4}: P1.26 (A20(D4)), U1.13 (A20/D4)
/CPU/D_{5}: P1.27 (A21(D5)), U1.12 (A21/D5)
/CPU/D_{6}: P1.28 (A22(D6)), U1.11 (A22/D6)
/CPU/D_{7}: P1.29 (A23(D7)), U1.10 (A23/D7)
/CPU/FIQ: CL1.1 (A), TP82.1, U1.124 (~FIQ)
/CPU/FL: C48.1, R7.2, R8.2, TP98.1
/CPU/FL1: C49.1, R8.1, TP100.1, U6.4 (LPFL1)
/CPU/FL2: C12.1, C48.2, TP101.1, U6.5 (LPFL2)
/CPU/FR: C11.1, R3.2, R4.2, TP99.1
/CPU/FR1: C10.1, R3.1, TP102.1, U6.2 (LPFR1)
/CPU/FR2: C9.1, C11.2, TP103.1, U6.3 (LPFR2)
/CPU/IN35: P1.C2, R5.1, TP75.1, U1.2 (IN35)
/CPU/IRQ: P1.31 (IRQ/DREQ), R6.2, U1.8 (IRQ)
/CPU/L-OUT: R30.1, TP115.1, U1.7 (SO2)
/CPU/LDB1: U1.101 (LDB1); also elsewhere on the board
/CPU/LDB2: U1.100 (LDB2); also elsewhere on the board
/CPU/LDB3: U1.99 (LDB3); also elsewhere on the board
/CPU/LDB4: U1.98 (LDB4); also elsewhere on the board
/CPU/LDB5: U1.97 (LDB5); also elsewhere on the board
/CPU/LDG1: U1.96 (LDG1); also elsewhere on the board
/CPU/LDG2: U1.95 (LDG2); also elsewhere on the board
/CPU/LDG3: U1.94 (LDG3); also elsewhere on the board
/CPU/LDG4: U1.93 (LDG4); also elsewhere on the board
/CPU/LDG5: U1.92 (LDG5); also elsewhere on the board
/CPU/LDR1: U1.91 (LDR1); also elsewhere on the board
/CPU/LDR2: U1.90 (LDR2); also elsewhere on the board
/CPU/LDR3: U1.89 (LDR3); also elsewhere on the board
/CPU/LDR4: U1.88 (LDR4); also elsewhere on the board
/CPU/LDR5: U1.87 (LDR5); also elsewhere on the board
/CPU/LGND: EM1.5, EM2.5, P4.6 (GND), P4.7 (SHIELD), P4.8 (SHIELD)
/CPU/LOUT: EM4.1, R20.2, TP109.1
/CPU/LP: U1.85 (LP); also elsewhere on the board
/CPU/MA_{0}: U1.45 (MA0), U2.25 (MA0)
/CPU/MA_{1}: U1.46 (MA1), U2.24 (MA1)
/CPU/MA_{2}: U1.47 (MA2), U2.23 (MA2)
/CPU/MA_{3}: U1.48 (MA3), U2.22 (MA3)
/CPU/MA_{4}: U1.49 (MA4), U2.21 (MA4)
/CPU/MA_{5}: U1.50 (MA5), U2.20 (MA5)
/CPU/MA_{6}: U1.51 (MA6), U2.19 (MA6)
/CPU/MA_{7}: U1.52 (MA7), U2.18 (MA7)
/CPU/MA_{8}: U1.56 (MA8), U2.8 (MA8)
/CPU/MA_{9}: U1.57 (MA9), U2.7 (MA9)
/CPU/MA_{10}: U1.58 (MA10), U2.6 (MA10)
/CPU/MA_{11}: U1.59 (MA11), U2.5 (MA11)
/CPU/MA_{12}: U1.60 (MA12), U2.4 (MA12)
/CPU/MA_{13}: U1.61 (MA13), U2.3 (MA13)
/CPU/MA_{14}: U1.62 (MA14), U2.2 (MA14)
/CPU/MA_{15}: U1.63 (MA15), U2.1 (MA15)
/CPU/MA_{16}: U1.74 (MA16), U2.48 (MA16)
/CPU/MD_{0}: U1.82 (MD0), U2.29 (MD0)
/CPU/MD_{1}: U1.80 (MD1), U2.31 (MD1)
/CPU/MD_{2}: U1.78 (MD2), U2.33 (MD2)
/CPU/MD_{3}: U1.76 (MD3), U2.35 (MD3)
/CPU/MD_{4}: U1.66 (MD4), U2.38 (MD4)
/CPU/MD_{5}: U1.68 (MD5), U2.40 (MD5)
/CPU/MD_{6}: U1.70 (MD6), U2.42 (MD6)
/CPU/MD_{7}: U1.72 (MD7), U2.44 (MD7)
/CPU/MD_{8}: U1.81 (MD8), U2.30 (MD8)
/CPU/MD_{9}: U1.79 (MD9), U2.32 (MD9)
/CPU/MD_{10}: U1.77 (MD10), U2.34 (MD10)
/CPU/MD_{11}: U1.75 (MD11), U2.36 (MD11)
/CPU/MD_{12}: U1.67 (MD12), U2.39 (MD12)
/CPU/MD_{13}: U1.69 (MD13), U2.41 (MD13)
/CPU/MD_{14}: U1.71 (MD14), U2.43 (MD14)
/CPU/MD_{15}: U1.73 (MD15), U2.45 (MD15)
/CPU/MOD: U1.107 (MOD); also elsewhere on the board
/CPU/PHI: P1.2 (PHI), TP77.1, U1.37 (PHI)
/CPU/PS: U1.86 (PS); also elsewhere on the board
/CPU/Q11B: C61.1, Q11.1 (B), TP35.1
/CPU/R-OUT: R31.1, TP114.1, U1.6 (SO1)
/CPU/RES: P1.30 (~CS2(~RES)), R2.2, R40.1, TP78.1
/CPU/RES_{0}: R40.2, U1.9 (~CS2)
/CPU/REVC: U1.108 (REVC); also elsewhere on the board
/CPU/ROUT: EM5.1, R19.2, TP110.1
/CPU/SCK: EM2.3, P4.5 (SCK), TP95.1
/CPU/SD: EM2.1, P4.4 (SD), TP93.1
/CPU/SI: EM1.3, P4.3 (SI), TP94.1
/CPU/SO: EM1.1, P4.2 (SO), TP92.1
/CPU/SP: C47.1, SP1.1, TP111.1, U6.19 (SPKOUT)
/CPU/SPL: U1.104 (SPL); also elsewhere on the board
/CPU/SPS: U1.106 (SPS); also elsewhere on the board
/CPU/TP0: SW4.2 (A), TP0.1, U1.4 (P0)
/CPU/TP1: SW4.1 (B), TP1.1, U1.5 (P1)
/CPU/TP2: SW5.2 (SEL), TP2.1, U1.126 (P2)
/CPU/TP3: SW5.1 (START), TP3.1, U1.127 (P3)
/CPU/TP4: SW6.2 (RIGHT), TP4.1, U1.123 (P4)
/CPU/TP5: SW6.4 (LEFT), TP5.1, U1.121 (P5)
/CPU/TP6: C62.2, SW6.1 (UP), TP6.1, U1.120 (P6)
/CPU/TP7: SW6.3 (DOWN), TP7.1, U1.122 (P7)
/CPU/TP8: C63.2, R43.2, TP8.1, U1.3 (P8)
/CPU/TP9: C64.2, R44.2, TP9.1, U1.119 (P9)
/CPU/U6-LIN: R7.1, R30.2, TP96.1, U6.8 (LIN)
/CPU/U6-LOUT: C45.1, R20.1, TP104.1, U6.15 (HPLOUT)
/CPU/U6-RIN: R4.1, R31.2, TP97.1, U6.7 (RIN)
/CPU/U6-ROUT: C46.1, R19.1, TP105.1, U6.17 (HPROUT)
/CPU/VOL: C59.1, TP106.1, U6.12 (VOL), VR2.2
/CPU/VR2-1: R14.2, TP108.1, VR2.1
/CPU/VR2-3: R37.2, TP107.1, VR2.3
/CPU/~CS: P1.5 (~CS1(~CS)), R39.1
/CPU/~CS_{0}: R39.2, U1.34 (~CS1)
/CPU/~LB: U1.53 (LB), U2.15 (~LB)
/CPU/~OE_{RAM}: U1.83 (MRD), U2.28 (~OE)
/CPU/~RD: P1.4 (~RD), U1.35 (~RD)
/CPU/~UB: U1.54 (UB), U2.14 (~UB)
/CPU/~WE_{RAM}: U1.55 (MWR), U2.11 (~WE)
/CPU/~WR: P1.3 (~WR), R38.1
/CPU/~WR_{0}: R38.2, U1.36 (~WR)
/VCNT5: U1.118 (R10); also elsewhere on the board
/~RESET: C30.2, EM7.1, Q11.3 (C), R29.1; also elsewhere on the board
GND: C3.1, C4.2, C5.2, C6.2, C7.2, C8.2, C9.2, C10.2, C12.2, C15.2, C16.2, C17.2, C18.2, C19.2, C20.2, C30.1, C34.2, C38.2, C39.2, C45.2, C46.2, C47.2, C49.2, C50.2, C51.2, C52.2, C53.2, C59.2, C62.1, C63.1, C64.1, CP4.2, EM1.6, EM2.6, P1.32 (GND), P3.4, Q11.2 (E), R5.2, R14.1, SW2.2, SW3.2, SW4.3 (GND), SW4.4 (GND), SW5.3 (GND), SW5.4 (GND), SW6.5 (GND), SW6.6 (GND), SW6.7 (GND), SW6.8 (GND), TP79.1, U1.39 (GND), U1.64 (GND), U1.102 (GND), U1.109 (TEST0), U1.110 (TEST1), U1.111 (TEST2), U1.112 (TEST3), U1.116 (GND), U1.128 (GND), U1.129 (NC(PAD)), U1.130 (NC(PAD)), U2.13 (NC/GND), U2.26 (~CE1), U2.27 (GND), U2.46 (GND), U6.6 (GND1), U6.20 (GND2); also elsewhere on the board
unnamed: C4.1, R41.2, X1.2
unnamed: EM4.2, P3.2
unnamed: EM5.2, P3.3
unnamed: EM6.2, P3.1
unnamed: EM3.2, P4.1 (VDD35)
unnamed: R43.1, SW3.1
unnamed: R44.1, SW2.1
unnamed: C19.1, EM1.2, RA1.1 (R1.1)
unnamed: RA1.2 (R1.2), U1.43 (SO)
unnamed: C18.1, EM1.4, RA1.3 (R2.1)
unnamed: RA1.4 (R2.2), U1.42 (SI)
unnamed: C20.1, EM2.2, RA1.5 (R3.1)
unnamed: RA1.6 (R3.2), U1.41 (SD)
unnamed: EM2.4, RA1.7 (R4.1)
unnamed: R35.1, RA1.8 (R4.2), U1.40 (SC)
unnamed: EM7.2, U1.125 (~RESET)
unnamed: C38.1, U6.1 (BC)
unnamed: P3.5, U6.13 (SW)
unnamed: C39.1, U6.9 (VREF)
VCC: C50.1, C51.1, R37.1, U6.16 (VCC1), U6.18 (VCC2); also elsewhere on the board
VDD2: C8.1, C15.1, C16.1, C52.1, C53.1, U1.44 (VDD2), U1.65 (VDD2), U1.115 (VDD2), U1.117 (VDD2), U2.12 (CE2), U2.16 (NC/VCC), U2.37 (VCC); also elsewhere on the board
VDD3: C5.1, C34.1, C61.2, CL1.2 (B), P1.S1, R6.1, R29.2, U1.1 (VDD3), U1.103 (VDD3); also elsewhere on the board
VDD5: P1.S2, U6.14 (~STB); also elsewhere on the board
VDD35: C6.1, C7.1, C17.1, EM3.1, P1.1 (VDD), P1.C1, R2.1, R35.2, TP76.1, U1.38 (VDD35)

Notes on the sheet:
RA1

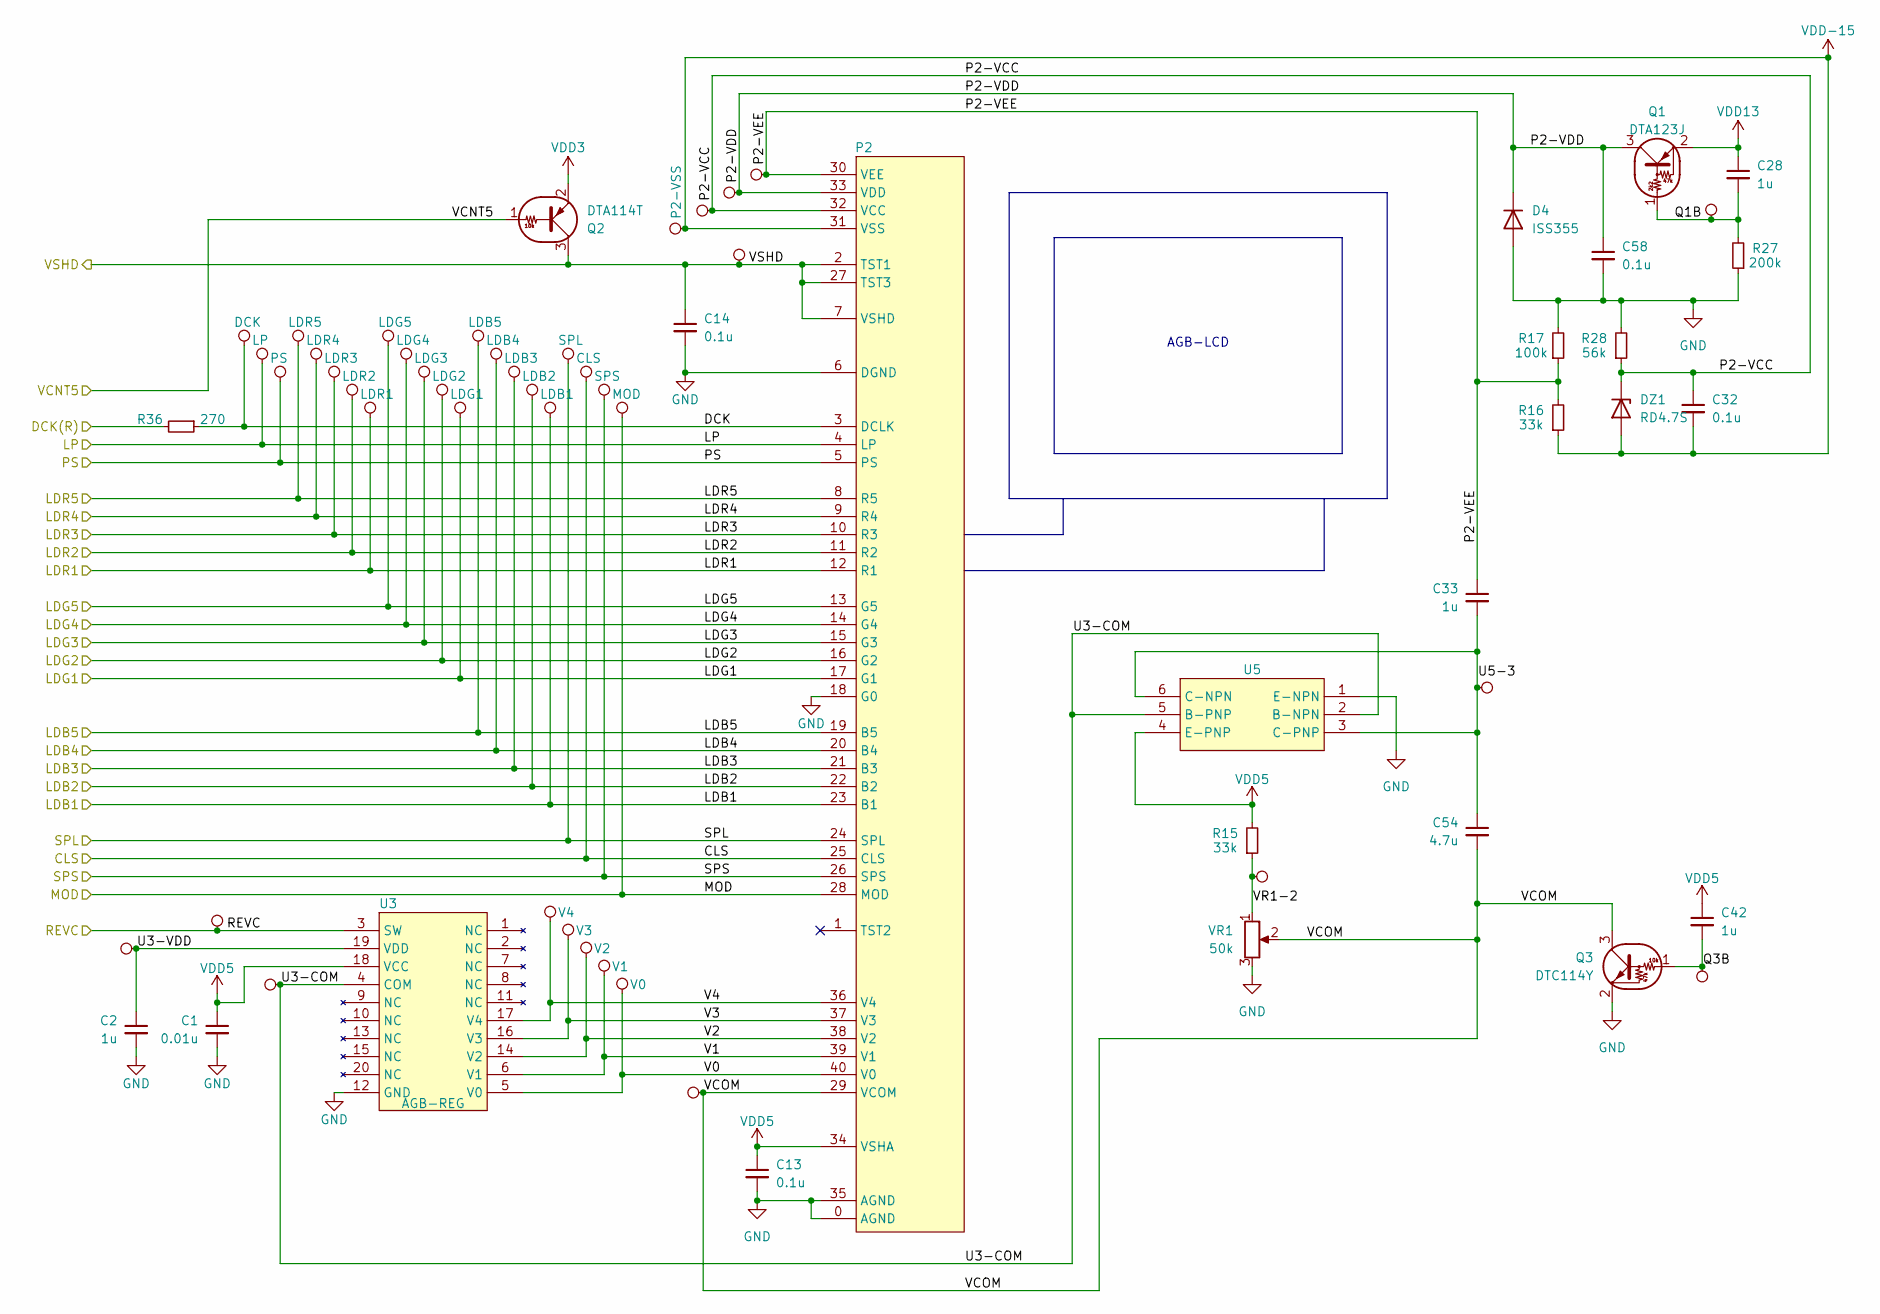
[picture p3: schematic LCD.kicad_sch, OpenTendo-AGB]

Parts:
C1: 0.01u; C_0402_1005Metric
C2, C28, C42: 1u; C_0603_1608Metric
C13, C14, C32, C58: 0.1u; C_0402_1005Metric
C33: 1u; C_0805_2012Metric
C54: 4.7u; C_0805_2012Metric
D4: ISS355; Diode
DZ1: RD4.7S; Diode
P2: LCD; LCD-Connector
Q1: DTA123J; SOT-323
Q2: DTA114T; SOT-323
Q3: DTC114Y; SOT-323
R15, R16: 33k; R_0402_1005Metric
R17: 100k; R_0402_1005Metric
R27: 200k; R_0402_1005Metric
R28: 56k; R_0402_1005Metric
R36: 270; R_0402_1005Metric
TP26: VSHD; TestPoint_Pad_D0.8mm
TP36: MOD; TestPoint_Pad_D0.8mm_VIA
TP37: SPS; TestPoint_Pad_D0.8mm_VIA
TP38: CLS; TestPoint_Pad_D0.8mm_VIA
TP39: SPL; TestPoint_Pad_D0.8mm_VIA
TP40: LDB1; TestPoint_Pad_D0.8mm_VIA
TP41: LDB2; TestPoint_Pad_D0.8mm_VIA
TP42: LDB3; TestPoint_Pad_D0.8mm_VIA
TP43: LDB4; TestPoint_Pad_D0.8mm_VIA
TP44: LDB5; TestPoint_Pad_D0.8mm_VIA
TP45: LDG1; TestPoint_Pad_D0.8mm_VIA
TP46: LDG2; TestPoint_Pad_D0.8mm_VIA
TP47: LDG3; TestPoint_Pad_D0.8mm_VIA
TP48: LDG4; TestPoint_Pad_D0.8mm_VIA
TP49: LDG5; TestPoint_Pad_D0.8mm_VIA
TP50: LDR1; TestPoint_Pad_D0.8mm_VIA
TP51: LDR2; TestPoint_Pad_D0.8mm_VIA
TP52: LDR3; TestPoint_Pad_D0.8mm_VIA
TP53: LDR4; TestPoint_Pad_D0.8mm_VIA
TP54: LDR5; TestPoint_Pad_D0.8mm_VIA
TP55: PS; TestPoint_Pad_D0.8mm_VIA
TP56: LP; TestPoint_Pad_D0.8mm_VIA
TP57: DCK; TestPoint_Pad_D0.8mm
TP58: P2-VSS; TestPoint_Pad_D0.8mm
TP59: P2-VCC; TestPoint_Pad_D0.8mm
TP60: P2-VDD; TestPoint_Pad_D0.8mm_VIA
TP61: P2-VEE; TestPoint_Pad_D0.8mm_VIA
TP62: REVC; TestPoint_Pad_D0.8mm
TP63: U3-VDD; TestPoint_Pad_D0.8mm
TP64: V0; TestPoint_Pad_D0.8mm
TP65: V1; TestPoint_Pad_D0.8mm
TP66: V2; TestPoint_Pad_D0.8mm
TP67: V3; TestPoint_Pad_D0.8mm_VIA
TP68: V4; TestPoint_Pad_D0.8mm
TP69: U3-COM; TestPoint_Pad_D0.8mm
TP70: VCOM; TestPoint_Pad_D0.8mm_VIA
TP71: VR1-2; TestPoint_Pad_D0.8mm_VIA
TP72: U5-3; TestPoint_Pad_D0.8mm_VIA
TP73: Q3B; TestPoint_Pad_D0.8mm_VIA
TP74: Q1B; TestPoint_Pad_D0.8mm_VIA
U3: AGB-REG
U5: UMD2N; SOT-363_SC-70-6
VR1: 50k; VR1

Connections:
/CPU/CLS: P2.25 (CLS), TP38.1; also elsewhere on the board
/CPU/DCK_{R}: R36.2; also elsewhere on the board
/CPU/LCD/DCK: P2.3 (DCLK), R36.1, TP57.1
/CPU/LCD/P2-VCC: C32.1, DZ1.1 (K), P2.32 (VCC), R28.1, TP59.1
/CPU/LCD/P2-VDD: C58.1, D4.1 (K), P2.33 (VDD), Q1.3 (C), TP60.1
/CPU/LCD/P2-VEE: C33.1, P2.30 (VEE), R16.2, R17.1, TP61.1
/CPU/LCD/Q1B: C28.2, Q1.1 (B), R27.2, TP74.1
/CPU/LCD/Q3B: C42.2, Q3.1 (B), TP73.1
/CPU/LCD/U3-COM: TP69.1, U3.4 (COM), U5.2 (B-NPN), U5.5 (B-PNP)
/CPU/LCD/U3-VDD: C2.1, TP63.1, U3.19 (VDD)
/CPU/LCD/U5-3: C33.2, C54.1, TP72.1, U5.3 (C-PNP), U5.6 (C-NPN)
/CPU/LCD/V0: P2.40 (V0), TP64.1, U3.5 (V0)
/CPU/LCD/V1: P2.39 (V1), TP65.1, U3.6 (V1)
/CPU/LCD/V2: P2.38 (V2), TP66.1, U3.14 (V2)
/CPU/LCD/V3: P2.37 (V3), TP67.1, U3.16 (V3)
/CPU/LCD/V4: P2.36 (V4), TP68.1, U3.17 (V4)
/CPU/LCD/VCOM: C54.2, P2.29 (VCOM), Q3.3 (C), TP70.1, VR1.2
/CPU/LCD/VR1-2: R15.1, TP71.1, VR1.1
/CPU/LDB1: P2.23 (B1), TP40.1; also elsewhere on the board
/CPU/LDB2: P2.22 (B2), TP41.1; also elsewhere on the board
/CPU/LDB3: P2.21 (B3), TP42.1; also elsewhere on the board
/CPU/LDB4: P2.20 (B4), TP43.1; also elsewhere on the board
/CPU/LDB5: P2.19 (B5), TP44.1; also elsewhere on the board
/CPU/LDG1: P2.17 (G1), TP45.1; also elsewhere on the board
/CPU/LDG2: P2.16 (G2), TP46.1; also elsewhere on the board
/CPU/LDG3: P2.15 (G3), TP47.1; also elsewhere on the board
/CPU/LDG4: P2.14 (G4), TP48.1; also elsewhere on the board
/CPU/LDG5: P2.13 (G5), TP49.1; also elsewhere on the board
/CPU/LDR1: P2.12 (R1), TP50.1; also elsewhere on the board
/CPU/LDR2: P2.11 (R2), TP51.1; also elsewhere on the board
/CPU/LDR3: P2.10 (R3), TP52.1; also elsewhere on the board
/CPU/LDR4: P2.9 (R4), TP53.1; also elsewhere on the board
/CPU/LDR5: P2.8 (R5), TP54.1; also elsewhere on the board
/CPU/LP: P2.4 (LP), TP56.1; also elsewhere on the board
/CPU/MOD: P2.28 (MOD), TP36.1; also elsewhere on the board
/CPU/PS: P2.5 (PS), TP55.1; also elsewhere on the board
/CPU/REVC: TP62.1, U3.3 (SW); also elsewhere on the board
/CPU/SPL: P2.24 (SPL), TP39.1; also elsewhere on the board
/CPU/SPS: P2.26 (SPS), TP37.1; also elsewhere on the board
/VCNT5: Q2.1 (B); also elsewhere on the board
/VSHD: C14.1, P2.2 (TST1), P2.7 (VSHD), P2.27 (TST3), Q2.3 (C), TP26.1; also elsewhere on the board
GND: C1.2, C2.2, C13.2, C14.2, C58.2, D4.2 (A), P2.0 (AGND), P2.6 (DGND), P2.18 (G0), P2.35 (AGND), Q3.2 (E), R17.2, R27.1, R28.2, U3.12 (GND), U5.1 (E-NPN), VR1.3; also elsewhere on the board
VDD3: Q2.2 (E); also elsewhere on the board
VDD5: C1.1, C13.1, C42.1, P2.34 (VSHA), R15.2, U3.18 (VCC), U5.4 (E-PNP); also elsewhere on the board
VDD13: C28.1, Q1.2 (E); also elsewhere on the board
VDD-15: C32.2, DZ1.2 (A), P2.31 (VSS), R16.1, TP58.1; also elsewhere on the board

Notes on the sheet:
AGB-LCD

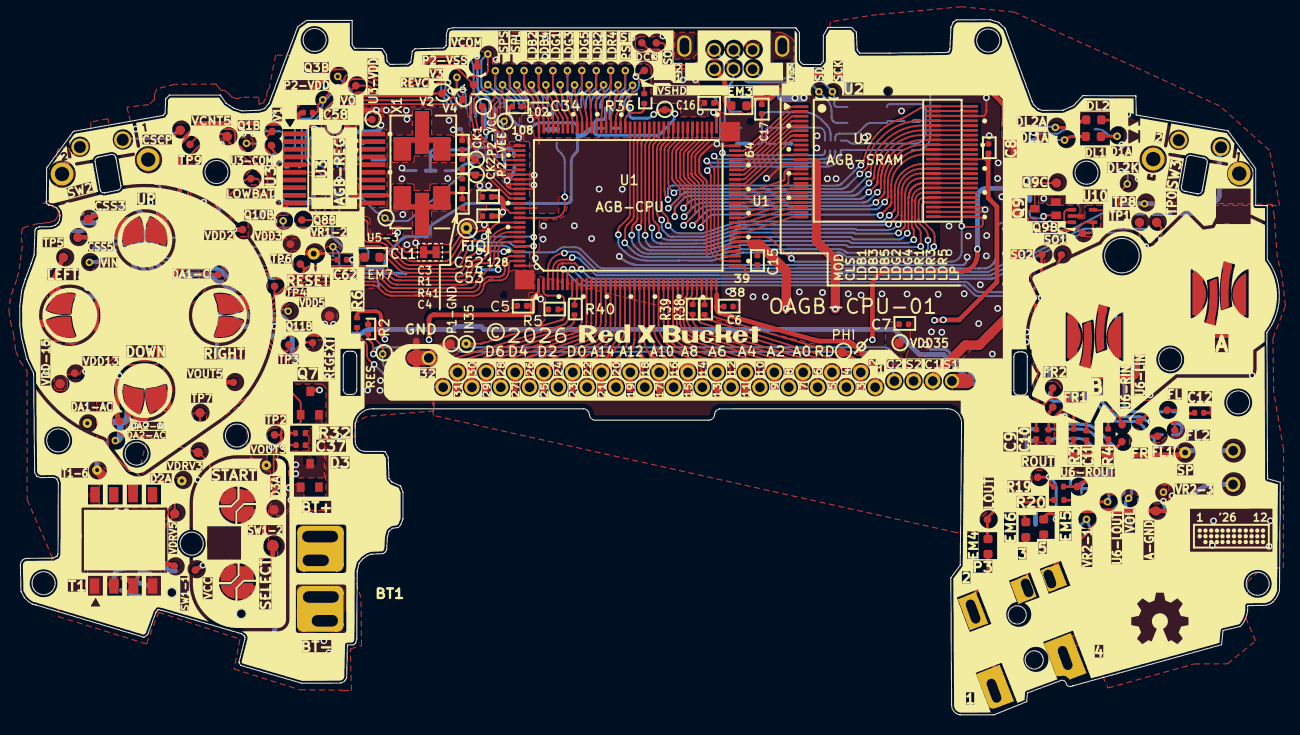
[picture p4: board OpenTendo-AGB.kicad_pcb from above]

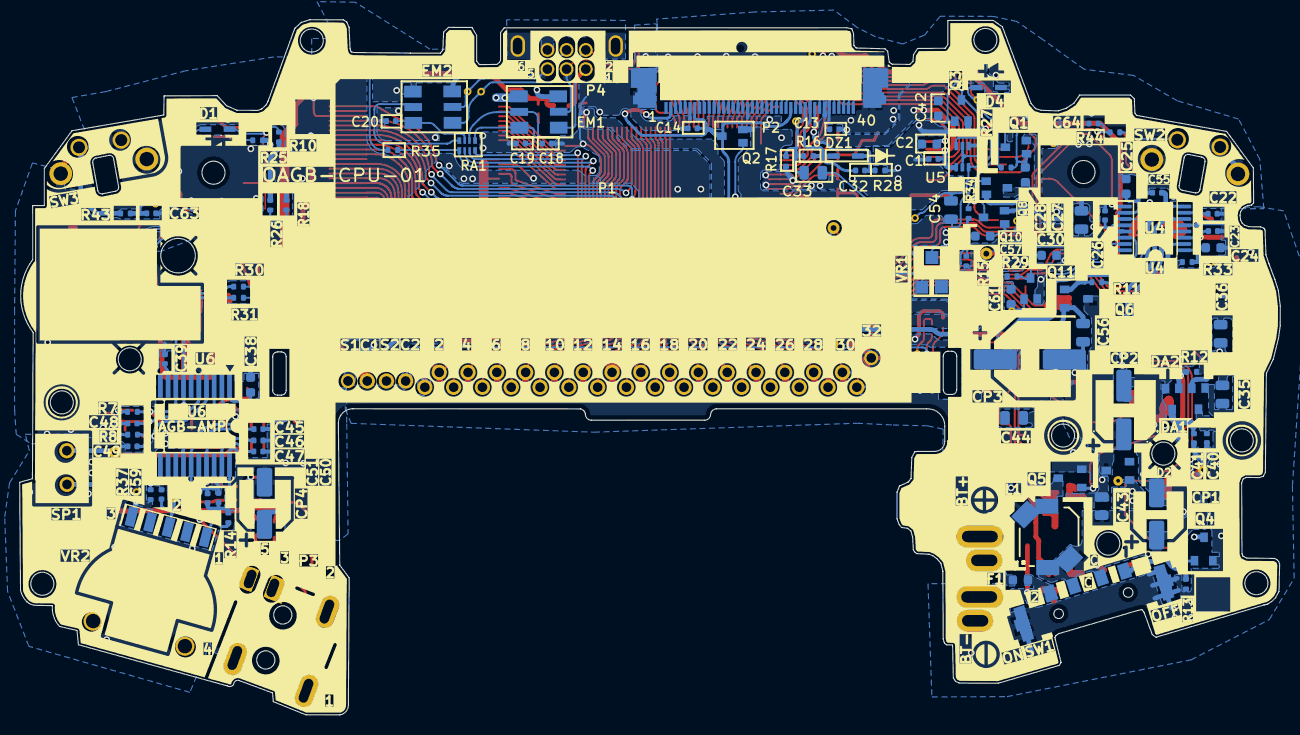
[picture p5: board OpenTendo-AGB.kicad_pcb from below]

Board: 2 copper layers, 131.3 x 72.4 mm, 273 parts (96 on the bottom side), 206 nets.

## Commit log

2023-01-30 + Add Kicad project files
    [OpenTendo-AGB.kicad_sch]
2025-12-31 Add .kicad_pcb file without images
    [OpenTendo-AGB.kicad_pcb]
